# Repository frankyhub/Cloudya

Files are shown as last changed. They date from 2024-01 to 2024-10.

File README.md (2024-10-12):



<div align="center">

|[:skull:ISSUE](https://github.com/frankyhub/Cloudya/issues?q=is%3Aissue)|[:speech_balloon: Forum /Discussion](https://github.com/frankyhub/Cloudya/discussions)|[:grey_question:WiKi](https://github.com/frankyhub/Cloudya/wiki)||
|--|--|--|--|
| | | | |
||<a href="https://github.com/frankyhub/Cloudya/issues">|<a href="https://github.com/frankyhub/Cloudya/discussions">|<a href="https://github.com/frankyhub/Cloudya/releases">|
|| <a href="https://github.com/frankyhub/Cloudya/pulse" alt="Activity">| <a href="https://github.com/frankyhub/Cloudya/graphs/traffic">  |<a href="https://github.com/frankyhub?tab=stars"> |
</div>

# Cloudya
Internetuhr, Wetterstation und RGB-Cloud

## Story
Diese Anleitung beschreibt den Aufbau der Internetuhr "Cloudya". Sie beinhaltet die Internetzeit, Sommer/Winterzeitumstellung, Weckfunktion, eine RGB-LED Cloud, einen WLAN-Manager und einen WEB-Server. Die Zeit- und Datumsanzeige erfolgt über ein 4-Digit TM1637 Display und ein OLED-Display. Die RGB-LED Cloud ist über den WEB-Server steuerbar, ebenso die Weckzeit, die Helligkeit des Displays und der RGB-LEDs.
Für die Einstellung der WLAN-Daten steht ein WLAN-Manager zur Verfügung. Nachdem in den Netzwerkeinstellungen des Handys/Tablet die "Cloudya" ausgewählt wurde, kann über die IP-Adresse 192.168.4.1 der WLAN-Manger gestartet und die WLAN-Zugangsdaten eingetragen werden. Sind die WLAN-Zugangsdaten korrekt, startet Claudya automatisch. Über die angezeigte IP-Adresse im OLED-Display ist der WEB-Server aufrufbar. Die Einstellungen sind jetzt über den WEB-Server möglich.

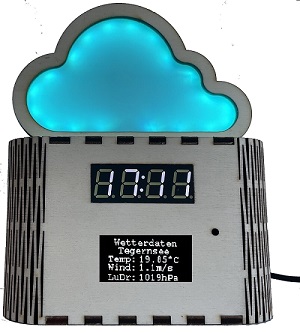
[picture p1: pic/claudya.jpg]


### Hardware

| Anzahl | Bezeichnung | 
| --- | --- |
|  1 | ESP32 NodeMCU D1 R32 |
|  1 |  ESP32 NodeMCU D1 R32 Shield |
|  1 |  Sperrholzplatte 300x600 x 4mm  |
|  1 | Cloudfolie weiß DIN A4 |
| 8  |  Platinenhalter (3D-Druck) |
|  2 | KY-012 Piezo Buzzer |
|  1 |  4-digits TM1637 Display 0,56" weiß  |
|  1 |  1,3 Zoll OLED Display I2C SSH1106 Chip  |
|  1 |  WS2812B LED Strip (NeoPixel)  |
| 1  | JST Stecker/Buchse |
| 1  | 4polige Crimpverbindung |
|  2 |  Stift/Buchsenleiste  |
| | Schaltdraht, Kleber, Kleinmaterial |
| ---  | --- |

### Aufbau und Montage

#### Die Cloud-Vorlage für den Lasercutter besteht aus:

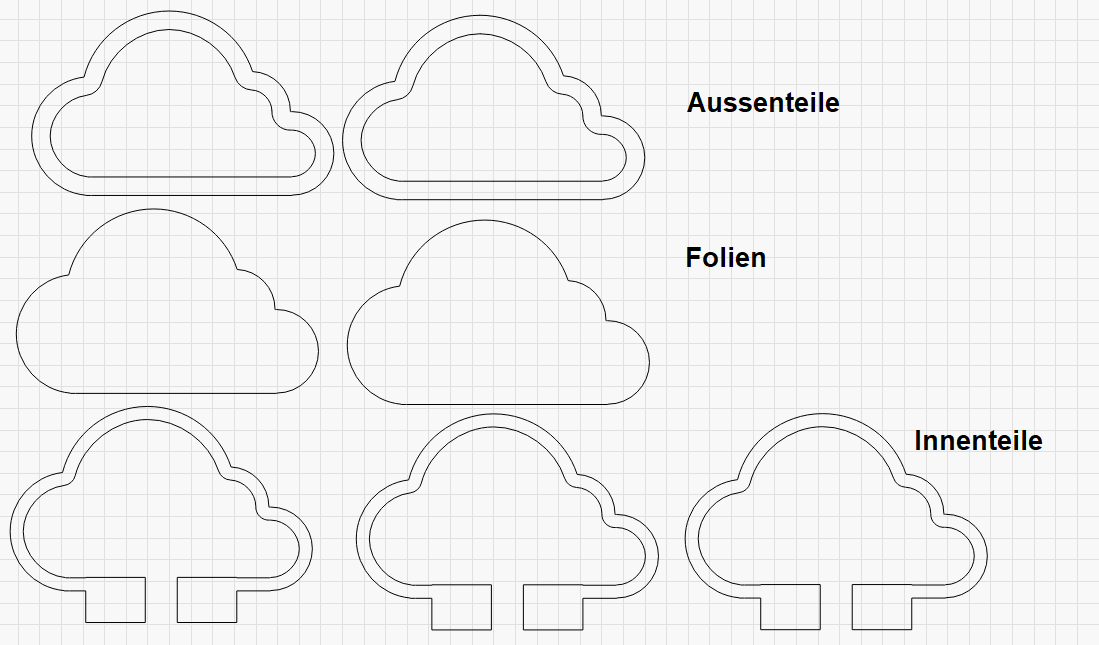
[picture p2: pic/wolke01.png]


### Die fertige Wolke besteht aus 5 Einzelteilen (4mm Sperrholz, L=140, Dicke: 20mm) und 2 Wolkenfolien:

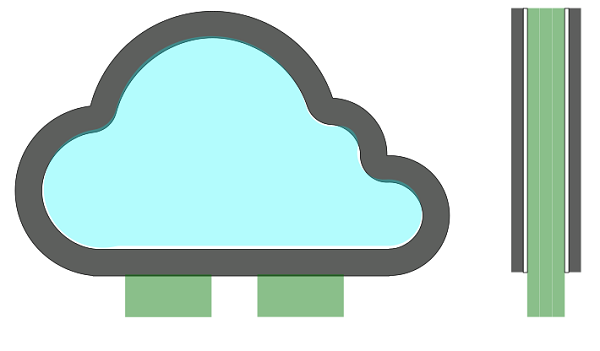
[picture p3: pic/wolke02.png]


### Erstelle die Wolkenteile mit Inkscape:

Zeichne mit den Abmessungen 140x85mm die Kreise der Wolke und unten ein Rechteck.

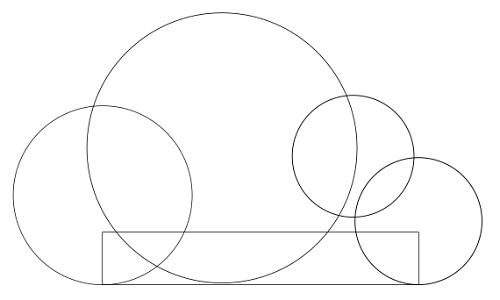
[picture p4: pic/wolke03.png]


### Markiere alles und bilde die Vereinigung. Pfad, Vereinigung (Strg++).

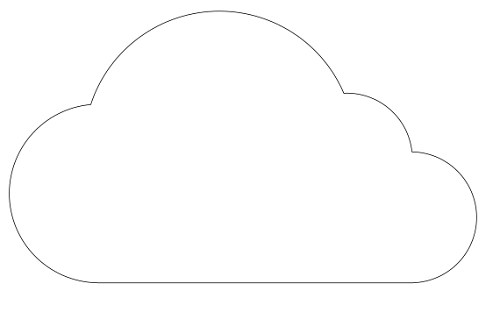
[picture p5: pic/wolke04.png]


### Dupliziere die Wolke 3x (Strg+D): 1x Sicherheitskopie und lege 2 Wolken deckungsgleich übereinander. Wähle eine Wolke aus und bilde den dynamischen Versatz. Pfad - Dynamischer Versatz (Strg+J)

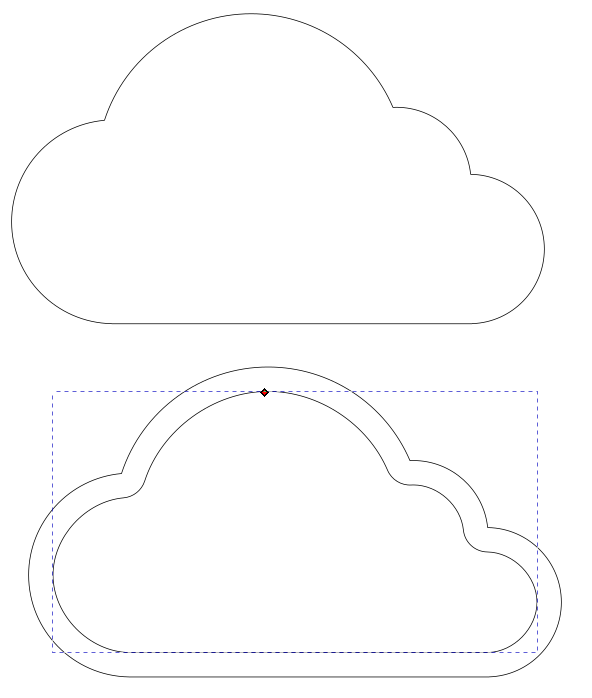
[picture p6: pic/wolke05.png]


### Markiere alles und bilde die Differenz - Pfad-Differenz (Strg+-). Dupliziere die Wolke 2x (Strg+D).

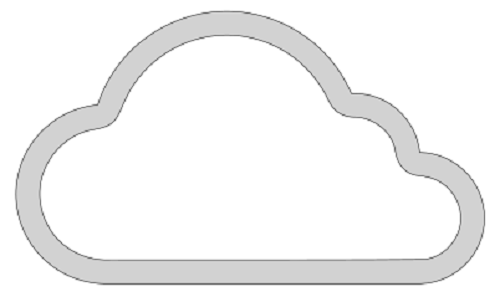
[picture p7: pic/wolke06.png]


### Erstelle mit der ersten Sicherheitskopie eine weitere Wolke mit einem kleineren Rand. Verwende erneut den dynamischen Versatz (Strg+J). Kopiere die Wolke 2x

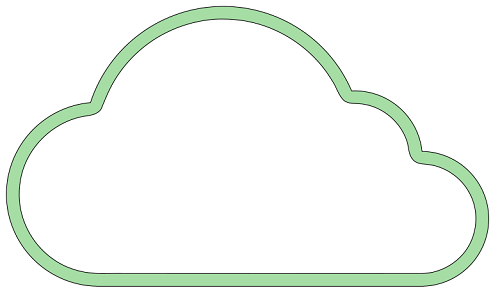
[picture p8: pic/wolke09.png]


### Zeichne ein Rechteck mit den Maßen 70x21mm und lege es unten auf die innere Wolke. Verbinde den schmalen Rahmen mit dem Rechteck- Pfad Vereinigung (Strg++)

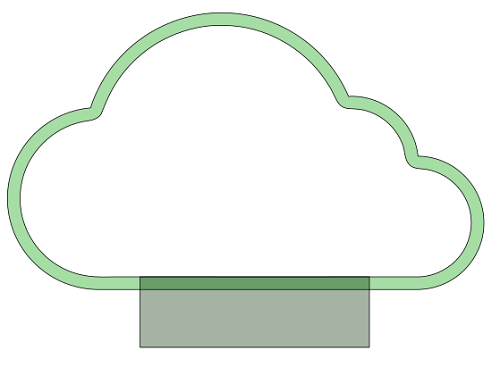
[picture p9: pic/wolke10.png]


### Zeichen ein Rechteck mit 15mm Breite, lege es mittig in die Wolke und bilde die Differenz (Strg+-)

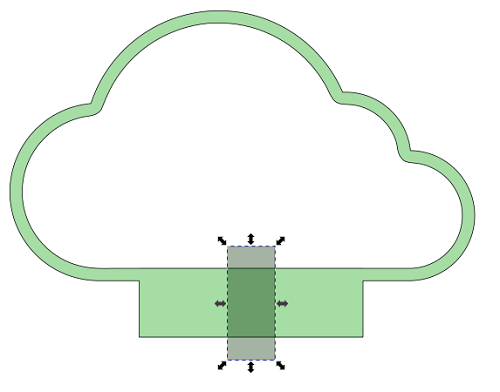
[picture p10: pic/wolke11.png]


### Kopiere die Wolke 3x

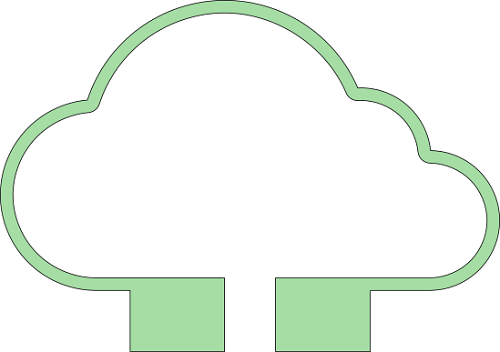
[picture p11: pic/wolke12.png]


### Jetzt sind alle Einzelteile fertig gezeichnet. Fertige von allen Zeichnungen eine Kopie und lege sie zur Kontrolle übereinander. Die Konturen der Wolken müssen deckungsgleich sein.

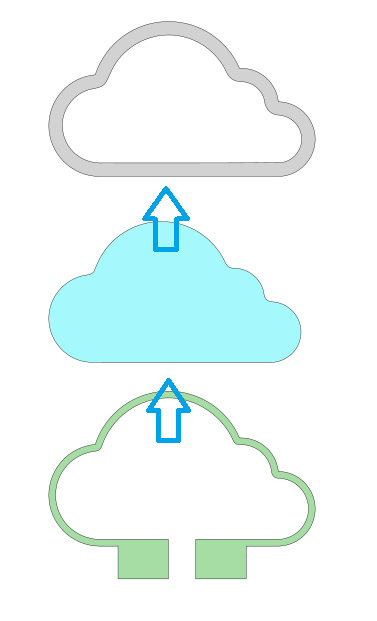
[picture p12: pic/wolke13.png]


### Die Wolken-Elemente liegen jetzt übereinander

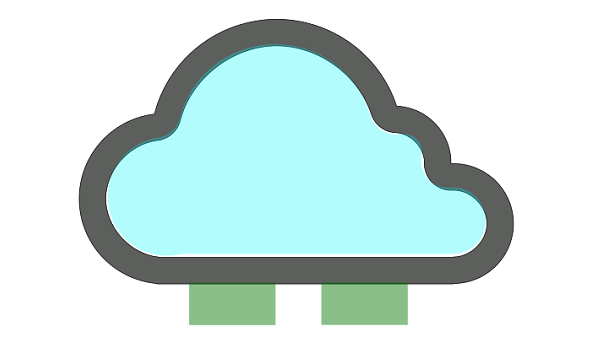
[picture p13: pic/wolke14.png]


### Jetzt sind alle Wolkenteile als Vorlage für den Lasercutter erstellt

Bild

### 3D-Druck, sieben Abstandshalter drucken
+ Die Abstandshalter tragen den ESP32, das 4-Digit-Display und das OLED-Display. Sie werden auf den ESP32, auf das 4-Digit-Display und auf das OLED-Display geklebt..
+ Erstelle die Abstandshalter mit Tinkercad.
+ Der Abstandshalter für das OLED-Display hat die Maße 44x34x2mm Der 1. Durchbruch hat das Maß 36x24x2 und der 2. Durchbruch hat das Maß 2x17x50

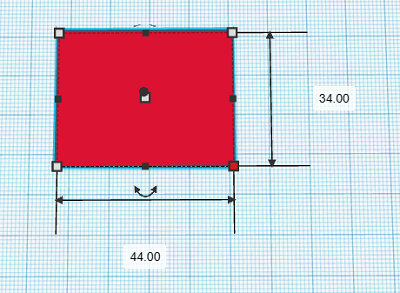
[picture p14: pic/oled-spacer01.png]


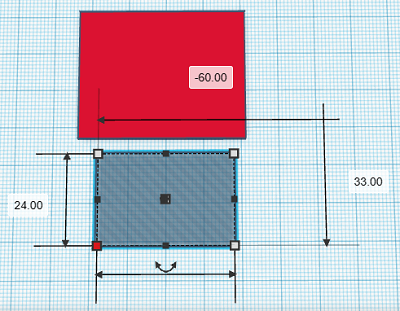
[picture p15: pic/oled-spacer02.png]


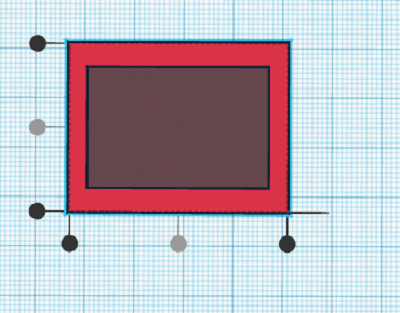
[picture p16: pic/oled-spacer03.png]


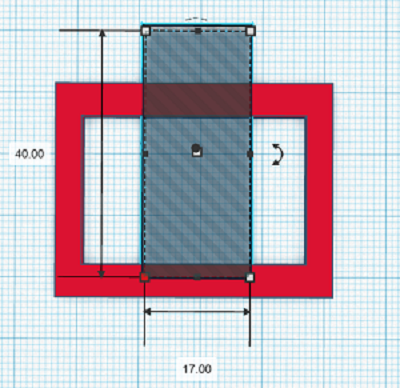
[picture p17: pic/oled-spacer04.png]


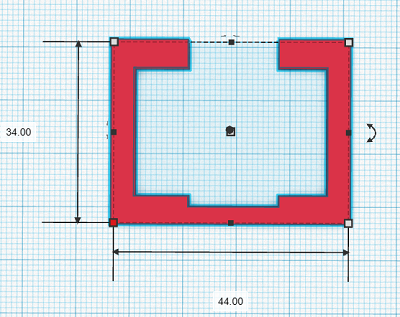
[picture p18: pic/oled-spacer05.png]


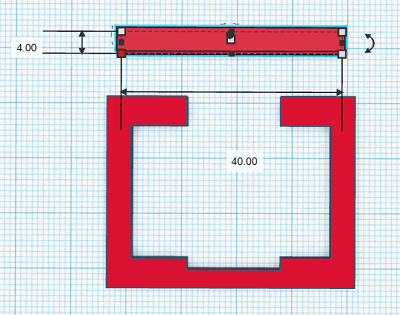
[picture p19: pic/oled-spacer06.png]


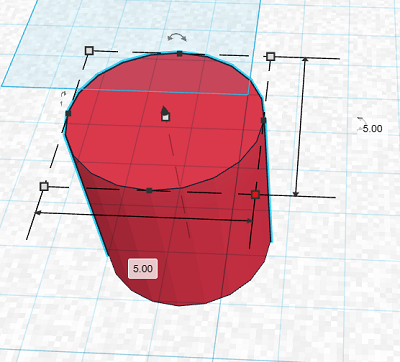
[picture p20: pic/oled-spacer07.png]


## Verdrahtung
+ OLED-Display 1,3": VDD an V, GND an G, SCK an SCL, SDA an SDA,
+ 4-stellige LED 0.56 Display: CLK an D18, DIO an D5, 5V an 5V, GND an GND
+ LED-Stripe: Data an D14, 5V an 5V, GND an GND
+ Buzzer Wecken  D4 und GND
+ Buzzer Gas D26 und GND
+ led_rot 25
+ led_gelb 17
+ led_gruen 16
+ DHT11  5V, GND, OUT an IO27
+ Gas Sensor MQ135 IO39 AO an IO39, 5V und GND; MQ135 eichen!

### ESP32 Shield

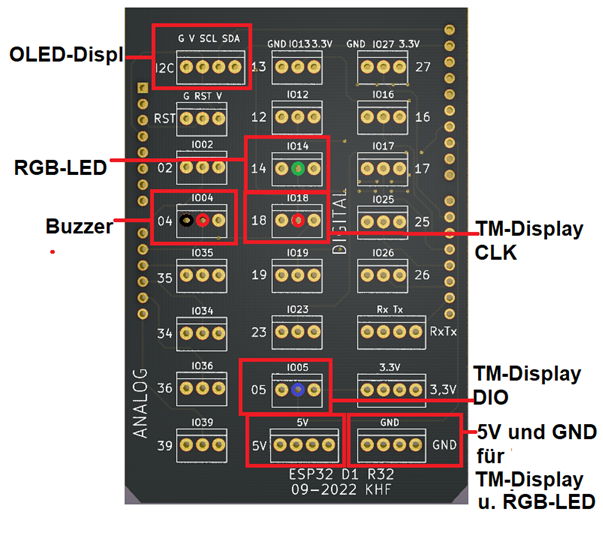
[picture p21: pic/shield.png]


### LED Display

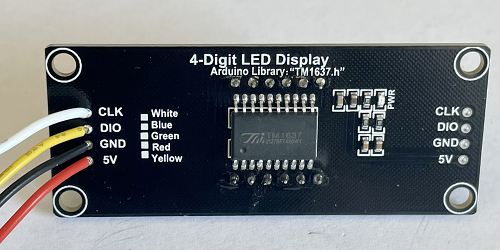
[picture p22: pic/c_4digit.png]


  ### DHT11

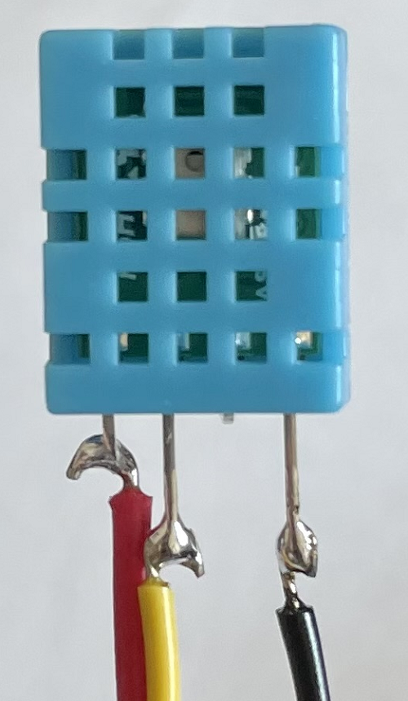
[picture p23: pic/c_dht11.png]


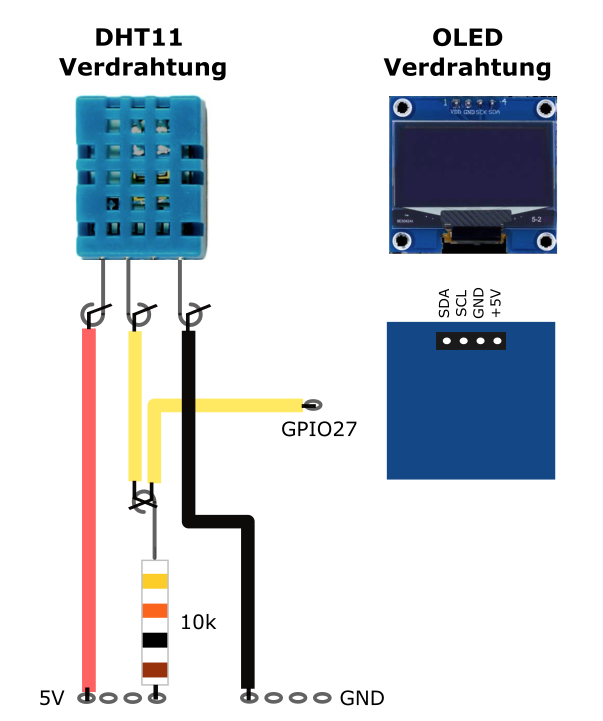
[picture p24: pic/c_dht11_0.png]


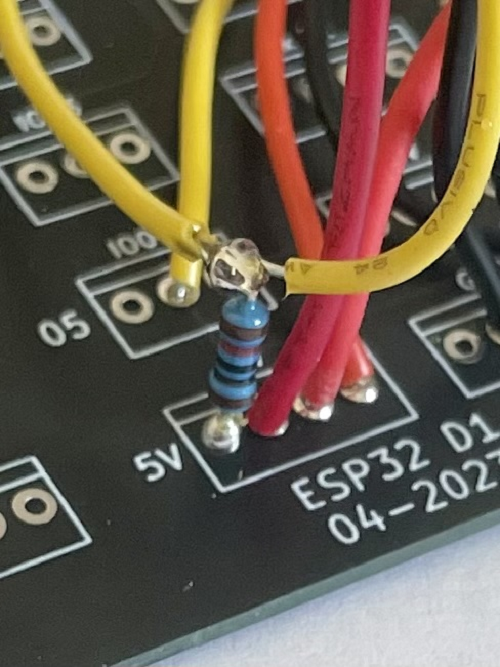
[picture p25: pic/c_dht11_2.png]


  ### LED Stripe

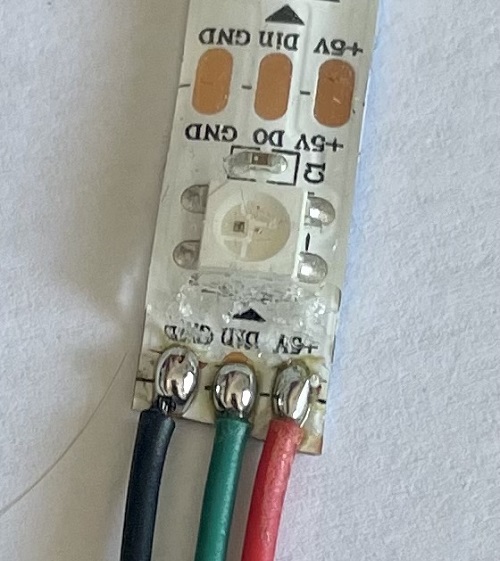
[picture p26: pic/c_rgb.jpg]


### Inbetriebnahme:

  1. Versorge deine Cloudya mit Strom
  2. Warte bis das "Cloudya" WLAN erscheint (Einstellungen, WLAN, Meine Netzwerke)
  3. Verbinde dich mit dem "Cloudya" WLAN und gebe 192.168.4.1 in der Adresszeile deines Webbrowsers ein (KEINE WEB/GOOGLE SUCHE)
  4. Du solltest jetzt ein Webinterface sehen in dem du den Namen und das Passwort deines Heimnetzwerks eingeben kannst
  5. Wenn du jetzt "Speichern" drückst, sollte sich deine Cloudya mit deinem Heimnetzwerk verbinden
  6. Die IP Adresse wird nach dem Reboot im OLED Display und im Seriellen Monitor angezeigt.
  7. Du kannst jetzt das Webinterface zur Steuerung des Lichts etc. aufrufen indem du die IP Adresse deiner Cloudya in der Adresszeile deines Webbrowsers eingibst.

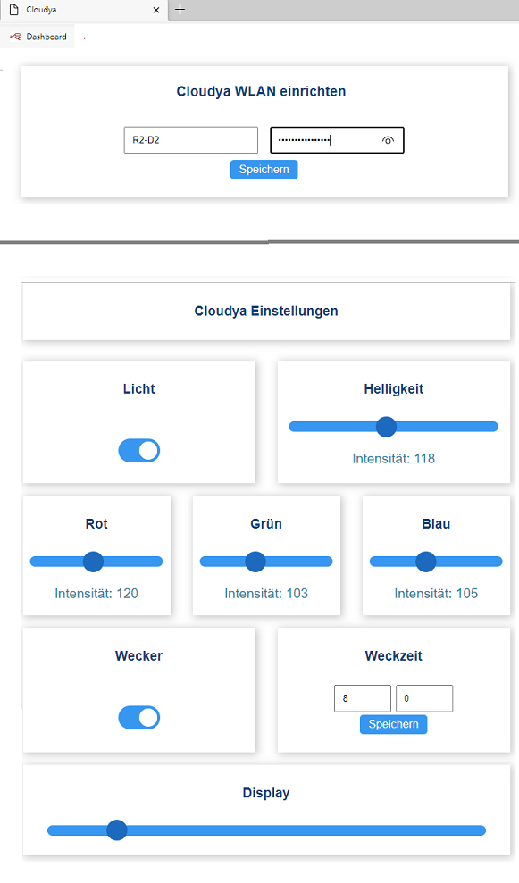
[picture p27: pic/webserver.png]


---

<div style="position:absolute; left:2cm; ">   
<ol class="breadcrumb" style="border-top: 2px solid black;border-bottom:2px solid black; height: 45px; width: 900px;"> <p align="center"><a href="#oben">nach oben</a></p></ol>
</div>  

---

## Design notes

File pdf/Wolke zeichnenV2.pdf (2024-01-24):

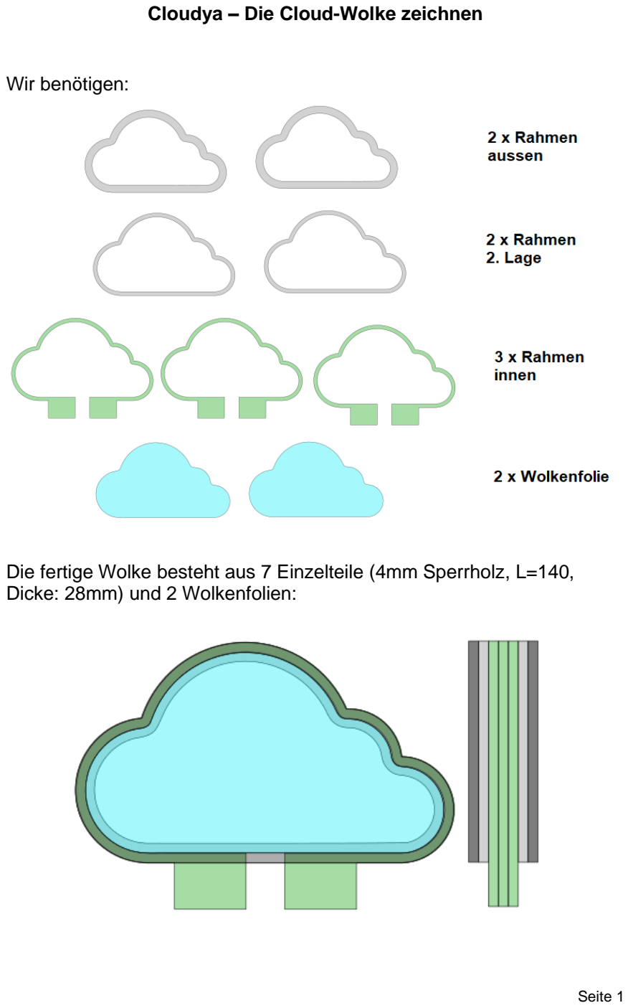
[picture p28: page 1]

Cloudya – Die Cloud-Wolke zeichnen

Wir benötigen:

Die fertige Wolke besteht aus 7 Einzelteile (4mm Sperrholz, L=140, Dicke: 28mm) und 2 Wolkenfolien:

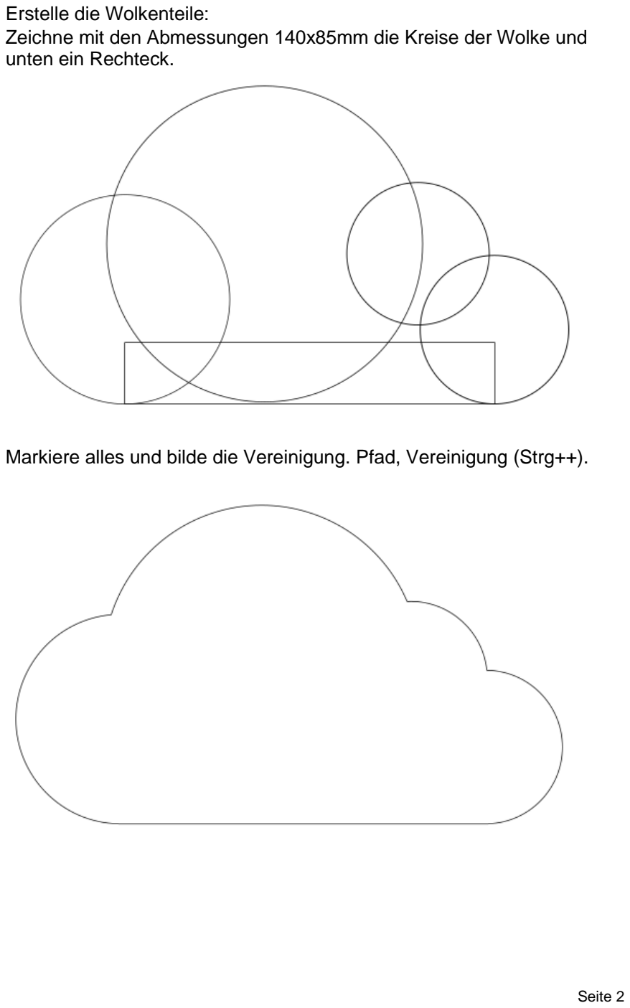
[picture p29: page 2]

Erstelle die Wolkenteile:
Zeichne mit den Abmessungen 140x85mm die Kreise der Wolke und unten ein Rechteck.

Markiere alles und bilde die Vereinigung. Pfad, Vereinigung (Strg++).

Dupliziere die Wolke 3x (Strg+D): 1x Sicherheitskopie und lege 2 Wolken deckungsgleich übereinander. Wähle eine Wolke aus und bilde den dynamischen Versatz. Pfad – Dynamischer Versatz (Strg+J)

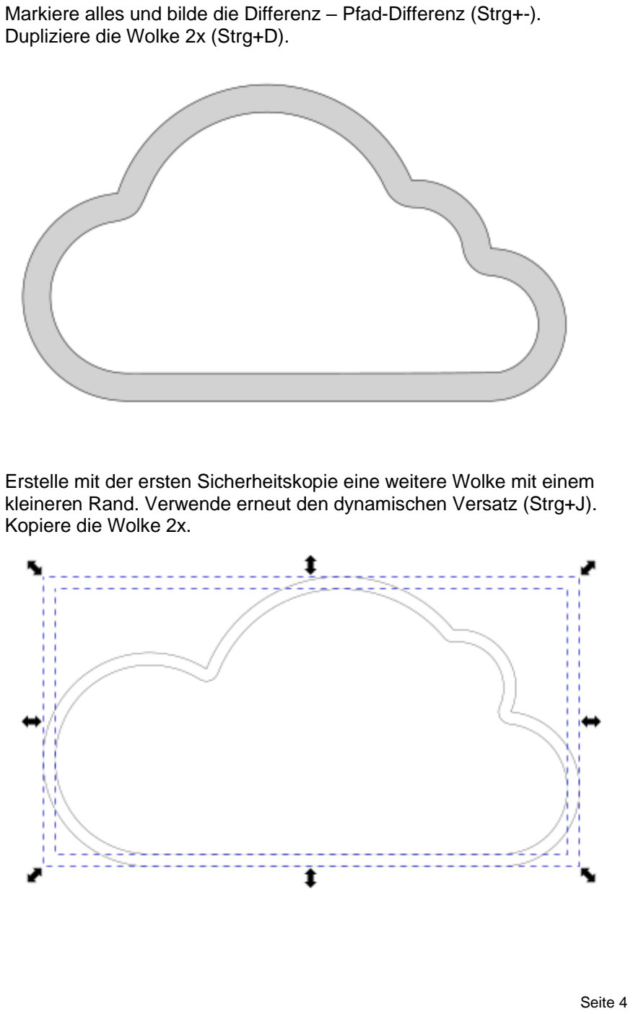
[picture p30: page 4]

Markiere alles und bilde die Differenz – Pfad-Differenz (Strg+-). Dupliziere die Wolke 2x (Strg+D).

Erstelle mit der ersten Sicherheitskopie eine weitere Wolke mit einem kleineren Rand. Verwende erneut den dynamischen Versatz (Strg+J). Kopiere die Wolke 2x.

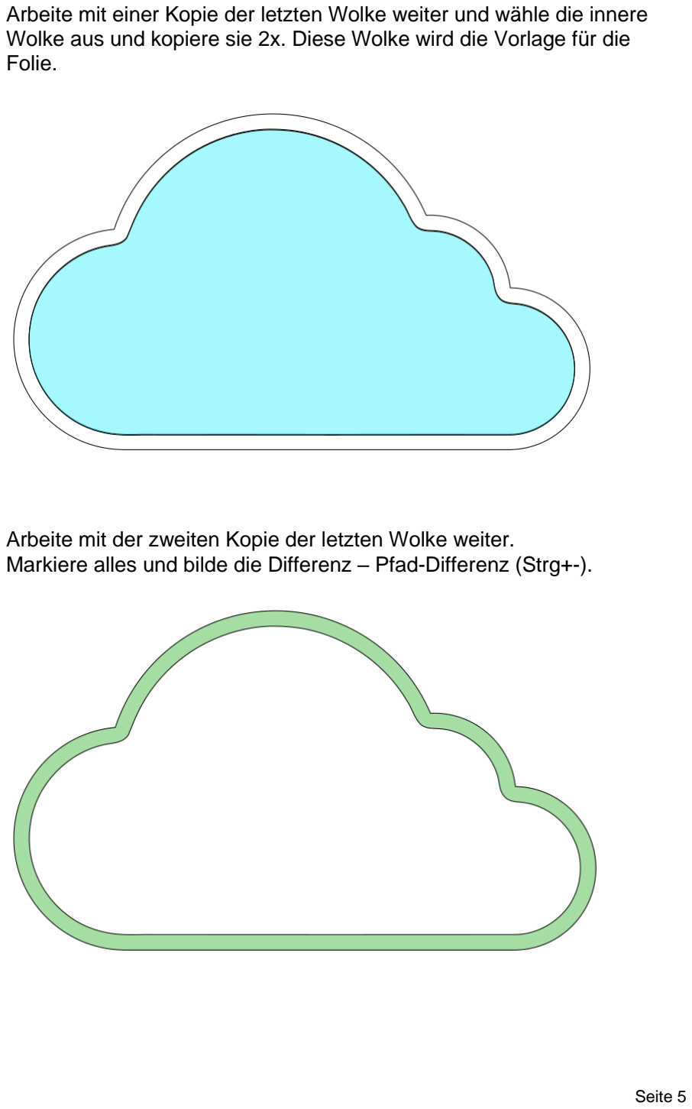
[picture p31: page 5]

Arbeite mit einer Kopie der letzten Wolke weiter und wähle die innere Wolke aus und kopiere sie 2x. Diese Wolke wird die Vorlage für die Folie.

Arbeite mit der zweiten Kopie der letzten Wolke weiter. Markiere alles und bilde die Differenz – Pfad-Differenz (Strg+-).

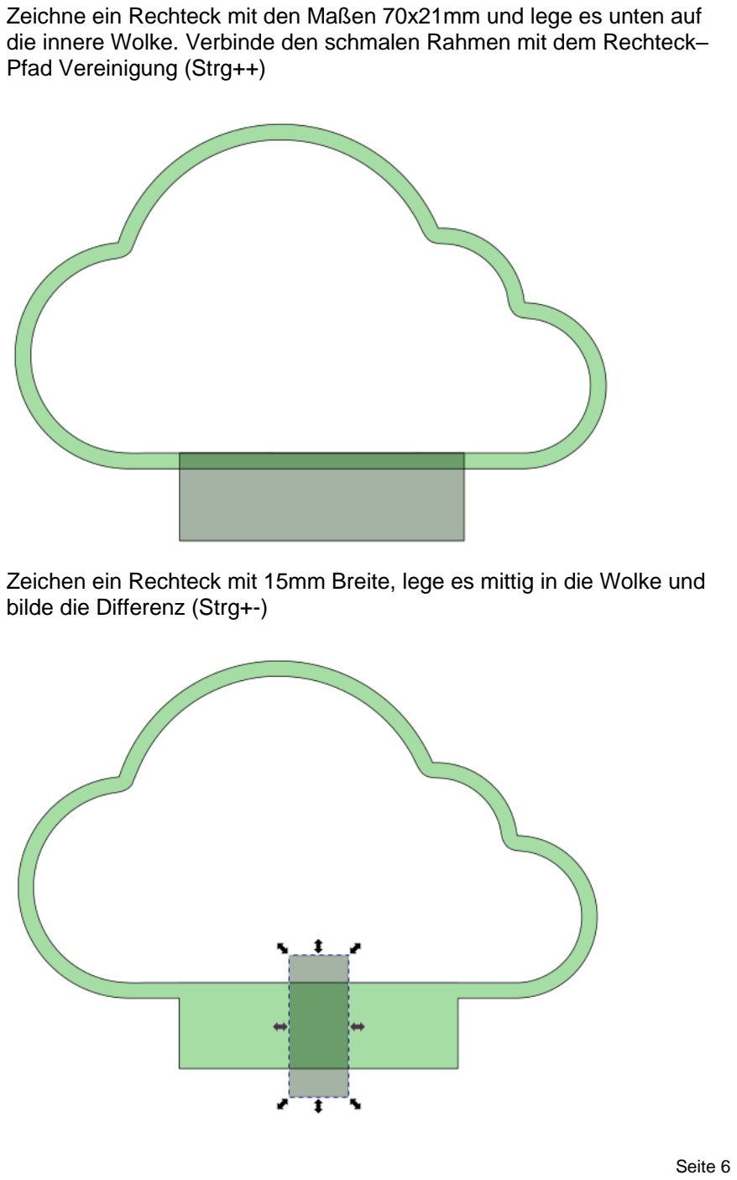
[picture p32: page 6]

Zeichne ein Rechteck mit den Maßen 70x21mm und lege es unten auf die innere Wolke. Verbinde den schmalen Rahmen mit dem Rechteck– Pfad Vereinigung (Strg++)

Zeichen ein Rechteck mit 15mm Breite, lege es mittig in die Wolke und bilde die Differenz (Strg+-)

Kopiere die Wolke 3x.

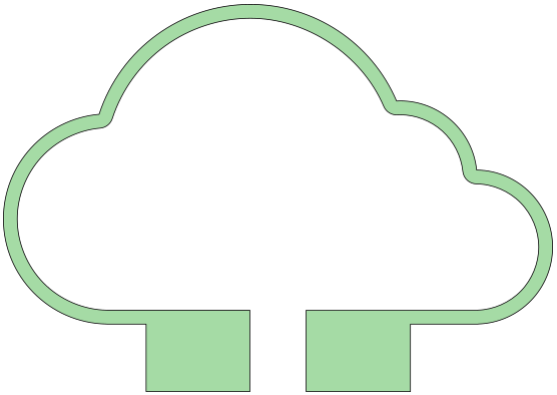
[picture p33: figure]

Jetzt sind alle Einzelteile fertig gezeichnet. Fertige von allen Zeichnungen eine Kopie und lege sie zur Kontrolle übereinander. Die Konturen der Wolken müssen deckungsgleich sein.

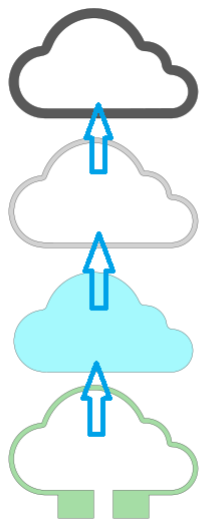
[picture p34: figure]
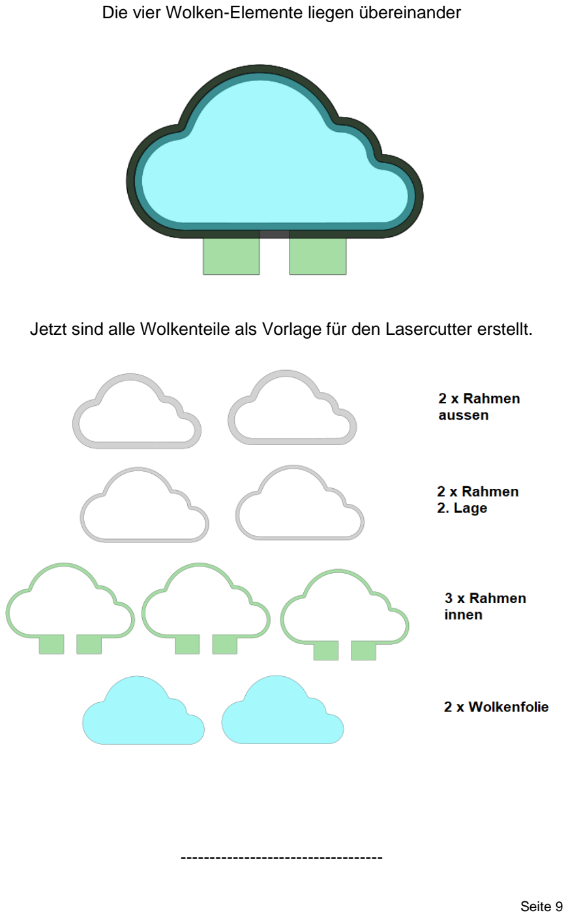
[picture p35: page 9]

Die vier Wolken-Elemente liegen übereinander

Jetzt sind alle Wolkenteile als Vorlage für den Lasercutter erstellt.

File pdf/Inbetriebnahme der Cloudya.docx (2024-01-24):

Inbetriebnahme der Cloudya

Die Cloudya zeigt die Uhrzeit, Datum, Raumtemperatur, Luftfeuchte und die aktuellen Wetterdaten in einem OLED-Display an und aktualisiert alles in regelmäßigen Abständen, Damit das funktioniert benötigt die Cloudya einen WLAN-Zugang.

Die Cloudya beinhaltet einen WiFi-Manager für die Einstellung der WLAN-Zugangsdaten (SSID und Passwort). Nach dem ersten Start der Cloudya, muss in den WLAN-Einstellungen des Handys, PC oder Tablet das Netzwerk " Cloudya " ausgewählt und über einen Browser die IP-Adresse 192.168.4.1 aufgerufen werden.

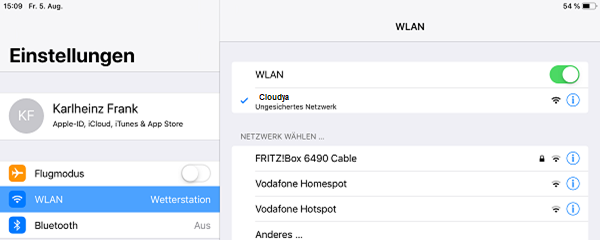
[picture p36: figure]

Danach startet "Cloudya WLAN einrichten" und die Zugangsdaten für das WLAN können eingetragen werden.

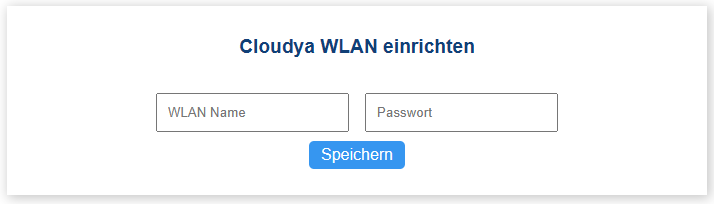
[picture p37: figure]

Sind die Zugangsdaten korrekt, startet Cloudya.
Die Cloudya zeigt beim Start für 5 Sekunden einen Smiley. In dieser Zeit werden die aktuelle Uhrzeit, das Datum und die aktuellen Wetterdaten aus der Region von de.pool.ntp.org und von openweathermap.org geladen.
Sind die Daten geladen, verschwindet der Smiley und es werden in regelmäßigen Abständen die Seiten mit Datum und Uhrzeit, die Wetterdaten der Region Tegernsee und das Raumklima mit Temperatur und Luftfeuchte angezeigt.

Auf der Startseite des OLED-Displays steht unten die IP Adresse für den Cloudya WEB-Server. Mit Eingabe dieser IP-Adresse in den Browser startet der Cloudya WEB-Server für die Einstellung des Weckers, der RGB-Farben und der Display-Helligkeit.

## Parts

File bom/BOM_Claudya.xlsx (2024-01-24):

 | BOM Claudya
Menge | Bezeichnung | Lieferant | Kosten | Kosten/Einheit
10 | ESP32 NodeMCU D1 R32 | AZ-Delivery (https://www.az-delivery.de/products/esp32-d1-r32-board) | 68.00 € | 6.80 € |  | YIXISI 20 Pairs JST SM 4PIN Stecker Männlich zu Weiblich EL Draht Kabel Stecker Adapter,2 Pin Stecker Männlichen und Weiblichen Steckverbinder Adapter mit 150 mm Elektrisch Kabel für LED Licht : Amazon.de: Baumarkt (https://www.amazon.de/gp/product/B08JV9L48T/ref=ox_sc_act_title_1?smid=A6CSVRKTUBQZZ&psc=1)
10 | KY-012 aktives Piezo Buzzer Alarm | Amazon (https://www.amazon.de/QWORK-Elektronischer-Summer-Active-Kabell%C3%A4nge/dp/B09RFH1T8J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) | 10.60 € | 0.50 €
10 | 4-Digit_LED-Display 0,56" TM1637 weiß | AliExpress (https://de.aliexpress.com/item/32838969764.html) | 19.54 € | 1.96 €
10 | WS2812B LED Strip (NeoPixel) | Amazon (https://www.amazon.de/dp/B01CDTEH3Q?aaxitk=82f2b46c5d5888f2d76393f048307f25&hsa_cr_id=3920940390402&pd_rd_pl) | 25.00 € | 2.50 €
10 | Polystyrol-Folie 0,5mm Art.Nr 0113648 | Modulor (https://www.modulor.de/polystyrol-weiss-matt-0-50-x-495-x-1000-nutzmass.html) | 9.50 € | 0.95 €
10 | TUOFENG 22 awg Volldraht | Amazon (https://www.amazon.de/TUOFENG-Volldraht-Volldraht-Kit-6-verschiedenfarbige-9-Meter-Spulen-Gauge-%C3%9Cberbr%C3%BCckungsdraht-Auflegungsdraht-Kit/dp/B07V5FVSYL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) | 21.00 € | 2.10 €
10 | 1,3 Zoll OLED Display I2C SSH1106 Chip | Amazon (https://www.amazon.de/AZDelivery-Display-Arduino-Raspberry-Gratis/dp/B07V9SLQ6W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) | 54.00 € | 5.40 €
10 | Stecker Netzteil für USB - HUB 7.5V, 2A Adapter Netzstecker Hohlstecker 5,5x2,1mm #417 | Amazon (https://www.amazon.de/SM-PC%C2%AE-Stecker-Netzteil-f%C3%BCr-USB/dp/B07S49STJD) | 70.00 € | 7.00 €
10 | JST Stecker Buchse | Amazon (https://www.amazon.de/gp/product/B08JV9L48T/ref=ppx_yo_dt_b_asin_image_o00_s00?ie=UTF8&psc=1) | 10.00 € | 1.00 €
10 | Platinenbuchsen | ebay (https://www.ebay.de/itm/283417689728)
10 | ESP32 Shield | JLCPBC | 20.00 € | 2.00 €
10 | Gehäuse Sperrholz 4mm | Laser cut |  | 5.00 €
10 | Abstandshalter | 3D-print |  | 1.00 €
20 | Stift/Buchsenleiste | Amazon (https://www.amazon.de/gp/product/B07CC4V9ZY/ref=ppx_yo_dt_b_search_asin_image?ie=UTF8&psc=1) | 9.87 € | 0.99 €
 |  |  |  | 37.20 €
 |  |  |  |  | 50 Stück Crimpkontakte für Platinenbuchse Raster 2,54mm | eBay (https://www.ebay.de/itm/283417671990)
 |  |  |  |  | 50 Stück Platinenbuchse Kabel-Platte Raster 2,54mm einreihig 4-polig | eBay (https://www.ebay.de/itm/283417689728)
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

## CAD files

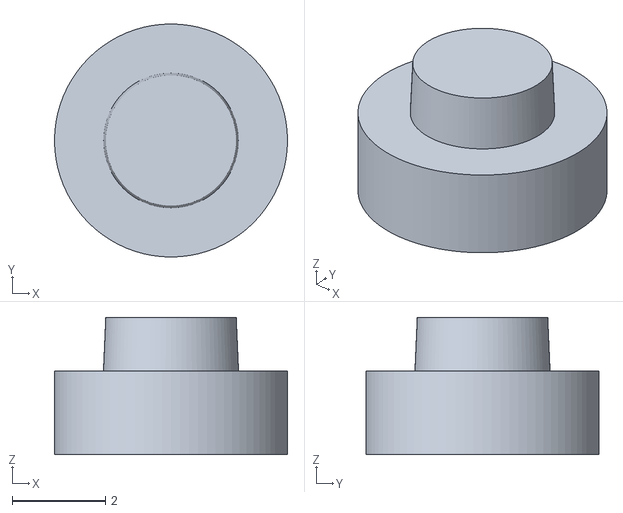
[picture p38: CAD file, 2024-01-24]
3D/Pin-Display.stl
5.00 x 5.00 x 2.95

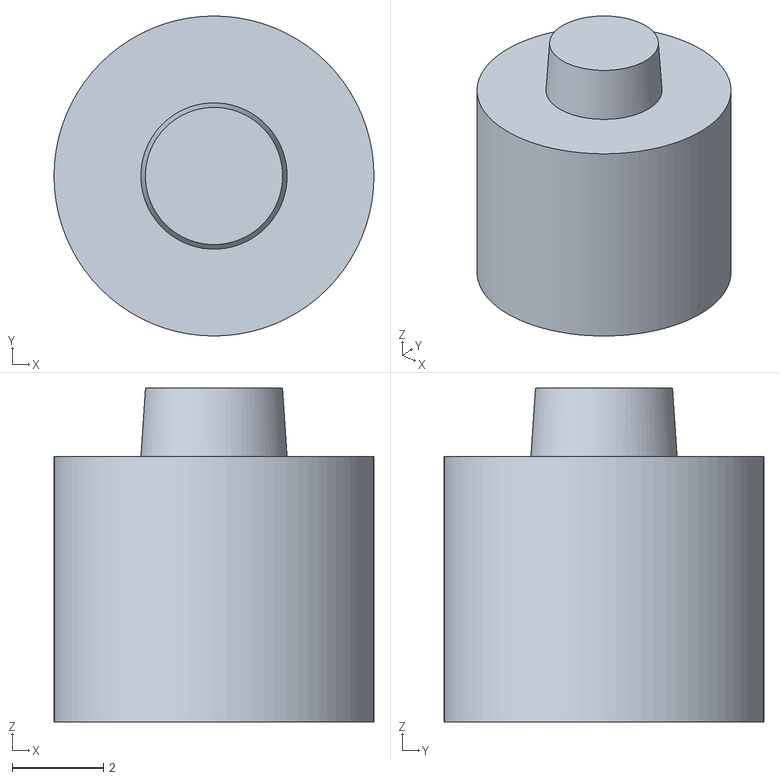
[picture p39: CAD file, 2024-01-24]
3D/Pin-SSegment.stl
7.00 x 7.00 x 7.30

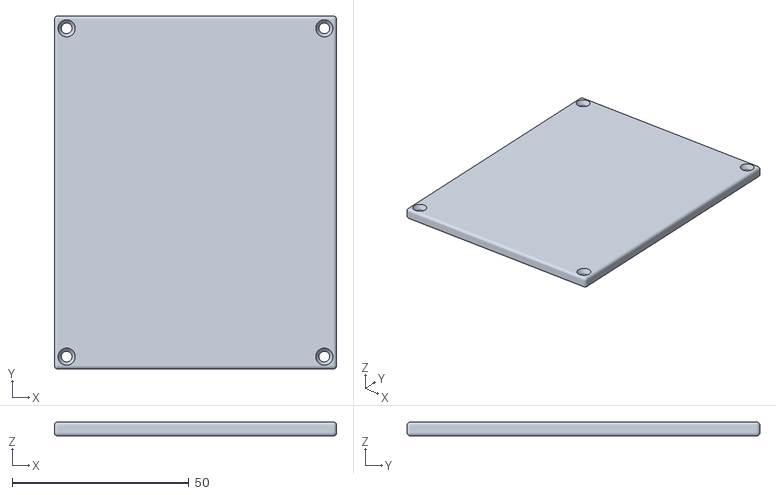
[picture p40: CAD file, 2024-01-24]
3D/Deckel-Time Cloud.stl
80.0 x 100.0 x 4.00

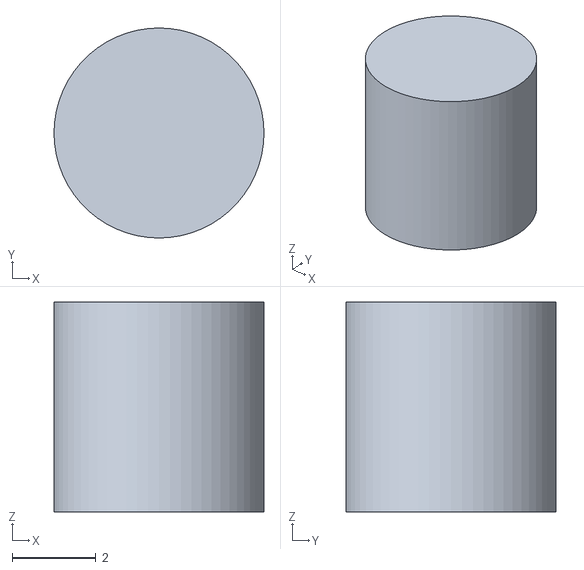
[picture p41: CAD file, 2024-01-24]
3D/Pin 5x5.stl
5.00 x 5.00 x 5.00

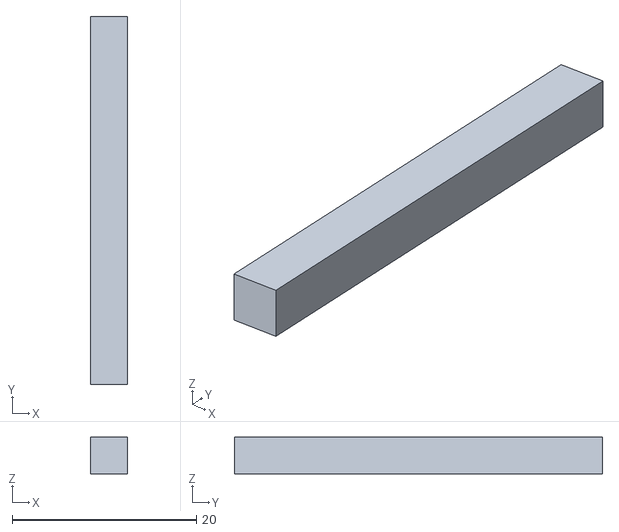
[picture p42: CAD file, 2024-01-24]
3D/TM-Spacer.stl
4.00 x 40.0 x 4.00

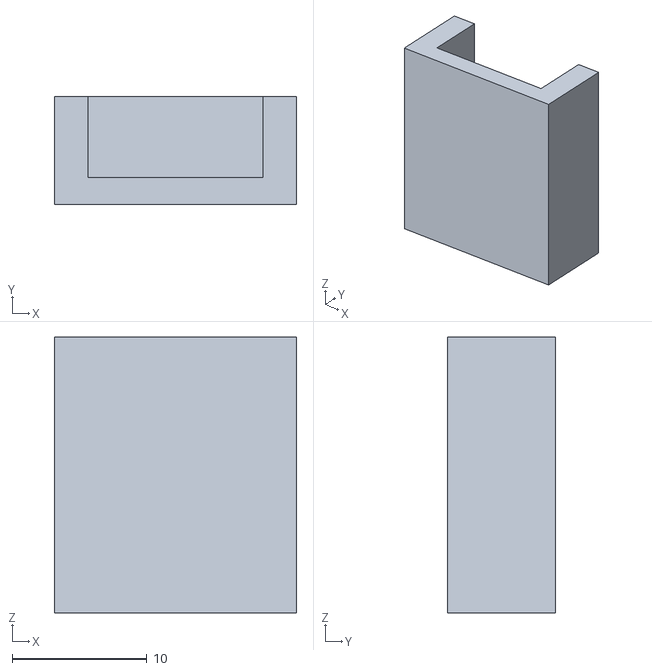
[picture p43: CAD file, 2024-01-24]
3D/DHT11-Halter.stl
18.0 x 8.00 x 20.5

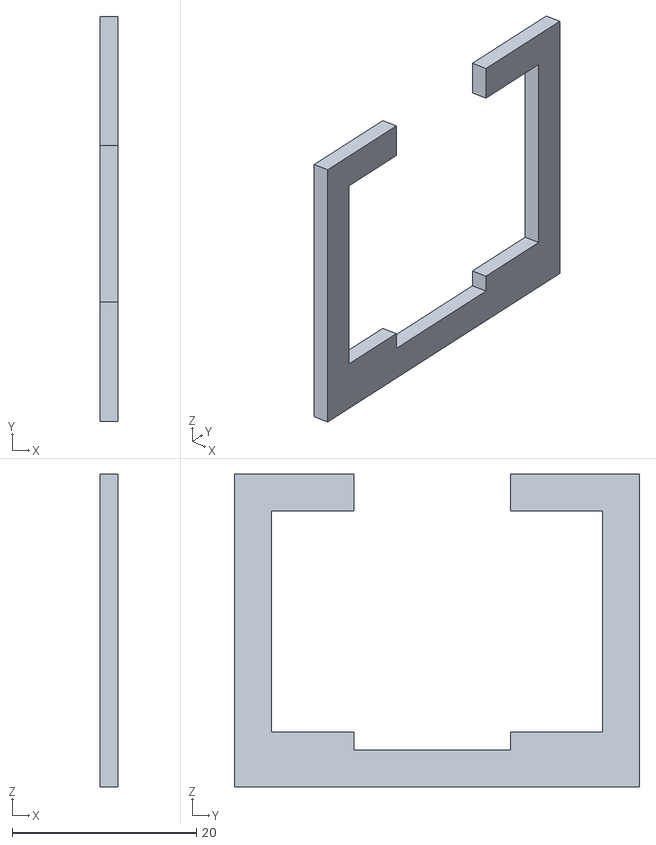
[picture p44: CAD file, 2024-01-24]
3D/OLED-Spacer1.stl
2.00 x 44.0 x 34.0

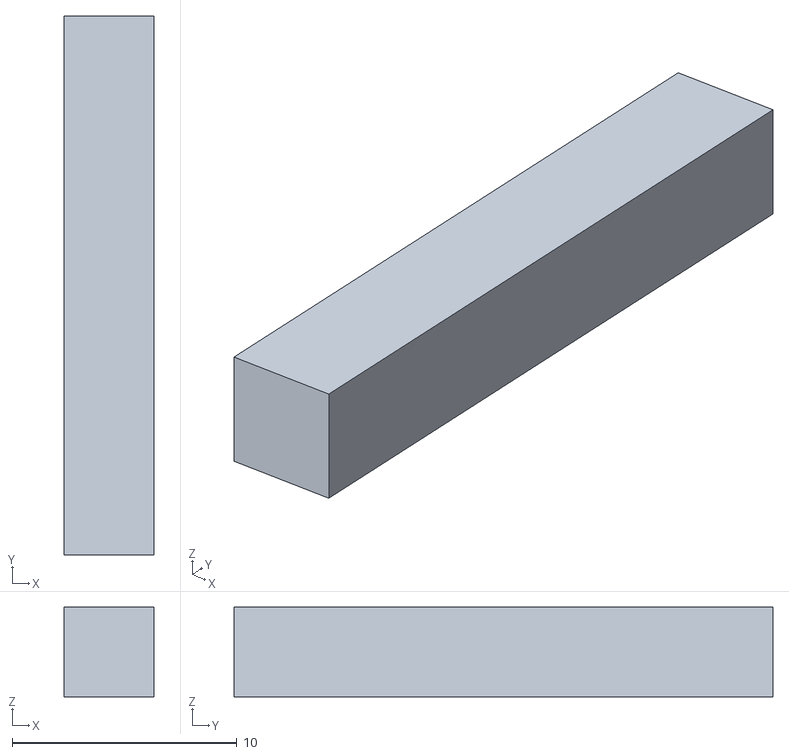
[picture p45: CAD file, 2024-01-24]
3D/alex-Spacer.stl
4.00 x 24.0 x 4.00

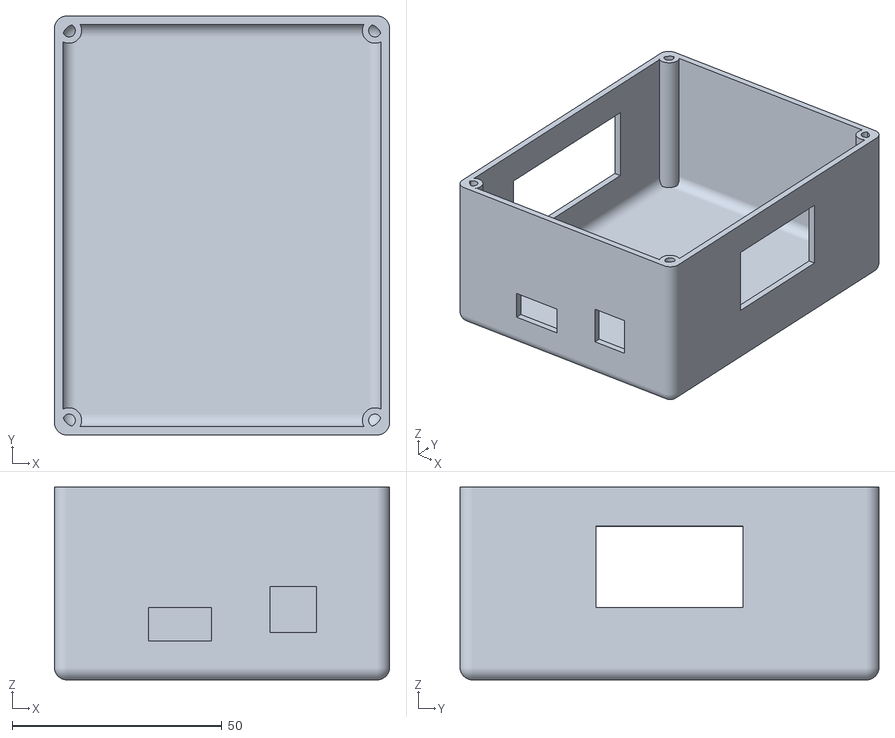
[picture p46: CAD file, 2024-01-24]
3D/Box-Cloudya.stl
80.0 x 100.0 x 46.0

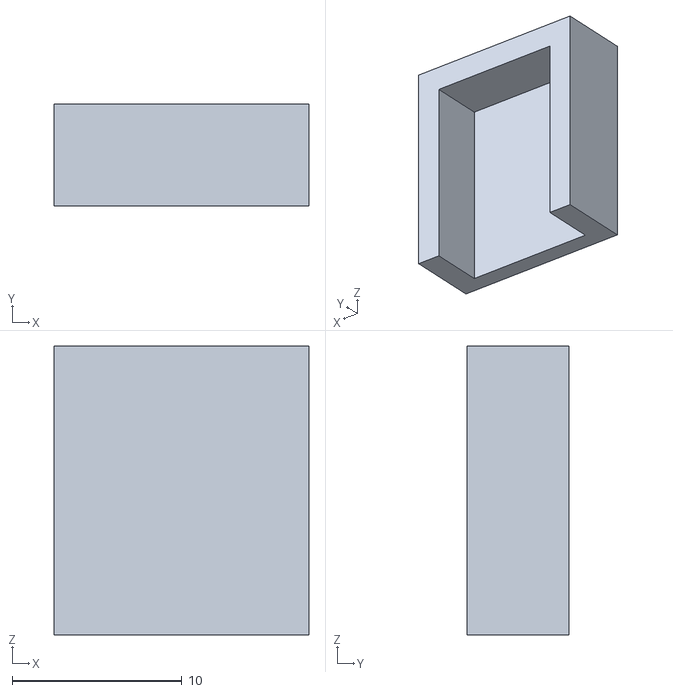
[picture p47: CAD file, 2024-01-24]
3D/DHT11-Halter_klein.stl
15.0 x 6.00 x 17.0

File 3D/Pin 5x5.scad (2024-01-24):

$fn=60;
cylinder(h=5,d=5);

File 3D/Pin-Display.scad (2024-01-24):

//Platinen Pin 

$fn=80;
Rgr = 2.5;  //Radius PIN 
R1kl = 1.5; //Radius 1 Stift
R2kl = 1.4; //Radius 2 Stift
Sh = 1.8;     //Sockelhöhe

color("WhiteSmoke")
cylinder(h = Sh, r1=Rgr , r2=Rgr , center = true); //Sockel
translate(v = [0, 0, Sh/2])
color("WhiteSmoke")
cylinder(h = 2.3, r1 = R1kl, r2 = R2kl, center = true); //Pin

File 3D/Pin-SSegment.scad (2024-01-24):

//Platinen Pin 

$fn=80;
Rgr = 3.5;  //Radius PIN 
R1kl = 1.7; //Radius 1 Stift
R2kl = 1.5; //Radius 2 Stift
Sh = 5.8;     //Sockelhöhe

color("WhiteSmoke")
cylinder(h = Sh, r1=Rgr , r2=Rgr , center = true); //Sockel
translate(v = [0, 0, Sh/2])
color("WhiteSmoke")
cylinder(h = 3, r1 = R1kl, r2 = R2kl, center = true); //Pin

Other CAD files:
3D/Deckel-Cloudya.stl
3D/Box-Cloudya.scad
3D/Box-Time Cloud50.scad
3D/DHT11-Halter.scad
3D/DHT11-Halter_klein.scad
3D/OLED-Spacer1.scad
3D/TM-Spacer.scad
3D/box/box_lib.scad
3D/box/compat.scad
3D/box/constants.scad
3D/box/math.scad
3D/box/shapes.scad
3D/box/transforms.scad

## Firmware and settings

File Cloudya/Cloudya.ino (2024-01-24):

/*************************************************************************************************
                                      PROGRAMMINFO
**************************************************************************************************
                                     Cloudya FP2023
  Funktion: ESP32 WEB Server Internet-Uhr, Wecker, LED-Stripe, 4 Digit Display, DHT11 Raumklima, Wetterdaten vom Tegernsee, Gas-Sensor
  OLED Display 1,3" mit Wochentag, Datum, Uhrzeit, Bewölkung und IP-Adresse, Raumklima, Wetterdaten

**************************************************************************************************
  Version: 01.03.2023   Cloudya A155
  ---------------------------------------------------------------

*************************************************************************************************
  Board: ESP32vn IoT UNO
**************************************************************************************************
  C++ Arduino IDE V1.8.19
**************************************************************************************************
  Einstellungen:
  https://dl.espressif.com/dl/package_esp32_index.json
  http://dan.drown.org/stm32duino/package_STM32duino_index.json
  https://raw.githubusercontent.com/espressif/arduino-esp32/gh-pages/package_esp32_dev_index.json
**************************************************************************************************
  Inbetriebnahme:

  1. Versorge deine Cloudya mit Strom
  2. Warte bis das "Cloudya" WLAN erscheint (Einstellungen, WLAN, Meine Netzwerke)
  3. Verbinde dich mit dem "Cloudya" WLAN und gebe 192.168.4.1 in der Adresszeile deines Webbrowsers ein (KEINE WEB/GOOGLE SUCHE)
  4. Du solltest jetzt ein Webinterface sehen in dem du den Namen und das Passwort deines Heimnetzwerks eingeben kannst
  5. Wenn du jetzt "Speichern" drückst, sollte sich deine Cloudya mit deinem Heimnetzwerk verbinden
  6. Die IP Adresse wird nach dem Reboot im OLED Display und im Seriellen Monitor angezeigt.
  7. Du kannst jetzt das Webinterface zur Steuerung des Lichts etc. aufrufen indem du die IP Adresse deiner Cloudya in der Adresszeile deines Webbrowsers eingibst.


  ### Electronik Verbindungen
**OLED-Display 1,3": VDD an V, GND an G, SCK an SCL, SDA an SDA,
**4-stellige LED 0.56 Display: CLK an D18, DIO an D5, 5V an 5V, GND an GND
**LED-Strip: Data an D14, 5V an 5V, GND an GND
**Buzzer Wecken  D4 und GND
**Buzzer Gas D26 und GND
** led_rot 25
** led_gelb 17
** led_gruen 16
** DHT11  5V, GND, OUT an IO27
** Gas Sensor MQ135 IO39 AO an IO39, 5V und GND; MQ135 eichen!
 **************************************************************************************************/

#include <AsyncTCP.h>
#include <ESPAsyncWebServer.h>
#include <ESPmDNS.h>
#include <FastLED.h>
#include <SPIFFS.h>
#include <TM1637Display.h>
#include <WiFi.h>
#include <time.h>
#include "./src/hardware/LightController.h"
#include "./src/network/MDNSController.h"
#include "./src/AlarmController.h"
#include "./src/PasswordController.h"
#include "./src/hardware/System.h"
#include "./src/Webserver.h"

//------------openWeatherMap--------------------------------
#include <HTTPClient.h>
#include <Arduino_JSON.h>
//---------------------------------------------------------


//------- Gas Sensor MQ135 ------------
int Buzzer = 26;
int Gas_analog = 39;
//int Gas_digital = 2;

#define led_rot 25
#define led_gelb 17
#define led_gruen 16
//----------------------------------------


//----------DHT11------------------------------------------
#include <SimpleDHT.h> //by Winlin 1.0.14       
int pinDHT11 = 27;
SimpleDHT11 dht11(pinDHT11);
//---------------------------------------------------------
#include <U8g2lib.h>
#include <Wire.h>

U8G2_SH1106_128X64_NONAME_F_HW_I2C u8g2(U8G2_R0, /* reset=*/ U8X8_PIN_NONE);
unsigned long delayTime;

#include <NTPClient.h>
#include <WiFiUdp.h>
WiFiUDP ntpUDP;
NTPClient timeClient(ntpUDP);

// Variablen
String formattedDate;
String dayStamp;
String timeStamp;
char *name = "Cloudya";
char *hostname = "Cloudya";
char *passwort = "";

// 4-Digit Display
#define CLK 18
#define DIO 5
TM1637Display display = TM1637Display(CLK, DIO);

// Internetzeit
#define MY_NTP_SERVER "de.pool.ntp.org"
#define MY_TZ "CET-1CEST,M3.5.0/02,M10.5.0/03" // https://github.com/nayarsystems/posix_tz_db/blob/master/zones.csv
time_t now;
tm tm;
void showTime() {
  time(&now);
  localtime_r(&now, &tm); // update the structure tm with the current time
  /* Serial.print("Jahr:");
    Serial.print(tm.tm_year + 1900); // years since 1900
    Serial.print("\tmonth:");
    Serial.print(tm.tm_mon + 1); // January = 0 (!)
    Serial.print("\tday:");
    Serial.print(tm.tm_mday); // day of month
    Serial.print("\thour:");
    Serial.print(tm.tm_hour); // hours since midnight 0-23
    Serial.print("\tmin:");
    Serial.print(tm.tm_min); // minutes after the hour 0-59
    Serial.print("\tsec:");
    Serial.print(tm.tm_sec); // seconds after the minute 0-61*
    Serial.print("\twday");
    Serial.print(tm.tm_wday); // days since Sunday 0-6
  */
  Serial.println();
}


MDNSController mdnsController = MDNSController(hostname, name);
LightController lightController = LightController();
AlarmController alarmController = AlarmController(&lightController);
Webserver webserver = Webserver(80, lightController, &alarmController, &display);
Webserver apWebserver = Webserver(80, lightController, &alarmController, &display);

bool isSetup = false;

struct Button
{
  uint8_t pin;
  uint32_t numberKeyPresses;
  bool pressed;
};

Button buttonRight = {12, 0, false};
Button buttonLeft = {33, 0, false};

void IRAM_ATTR buttonRightIRS()
{
  buttonRight.numberKeyPresses += 1;
  buttonRight.pressed = true;
}

void IRAM_ATTR buttonLeftIRS()
{
  buttonLeft.numberKeyPresses += 1;
  buttonLeft.pressed = true;
}

//----------------OLED Clock----------------------------
// Define NTP Client to get time

//Wochentage
String weekDays[7] = {"Sonntag", "Montag", "Dienstag", "Mittwoch", "Donnerstag", "Freitag", "Samstag"};

//Monate
String months[12] = {"Jan", "Feb", "M""\xE4""rz", "Apr", "Mai", "Juni", "Juli", "Aug", "Sept", "Okt", "Nov", "Dez"};
//-----------------------------------------------

//char tag[7] = {'Sonntag', 'Montag ', 'Dienstag', 'Mittwoch', 'Donnerstag', 'Freitag', 'Samstag'};

//--------------Wetter-----------------------------------------------
String openWeatherMapApiKey = "b2bc7fc61c4cc3545e6bbf151b58e1dd";
String city = "Tegernsee";
String countryCode = "DE";

unsigned long lastTime = 0;
// Timer  10 Minuten (600000)
//unsigned long timerDelay = 600000;
// Timer 10 Sekunden (10000)
unsigned long timerDelay = 10000;

String jsonBuffer;
int ktemp;
int mintemp;
int maxtemp;
int sicht;
//------------------------------------------------------------------------


void setup() //-------------------------------------------------------------------------------------------------------------
{
  //------- Gas Sensor MQ135 ------------
  pinMode(Buzzer, OUTPUT);
  //    pinMode(Gas_digital, INPUT);

  pinMode(led_rot, OUTPUT);
  pinMode(led_gruen, OUTPUT);
  pinMode(led_gelb, OUTPUT);
  //----------------------------------------


  u8g2.begin();
  Serial.begin(115200);
  // setup display
  display.setBrightness(0); // Set the display brightness (0-7)!!!!!
  display.clear();          // Clear the display

  System::initFS();

  PasswordController passwordController = PasswordController("/wifi.txt");

  pinMode(buttonRight.pin, INPUT_PULLUP);
  pinMode(buttonLeft.pin, INPUT_PULLUP);
  attachInterrupt(buttonRight.pin, buttonRightIRS, FALLING);
  attachInterrupt(buttonLeft.pin, buttonLeftIRS, FALLING);

  if (!passwordController.isExisting())
  {
    isSetup = true;
  }
  else
  {
    isSetup = !System::connectToWifi(&passwordController);
  }

  if (isSetup)
  {
    WiFi.disconnect();
    WiFi.mode(WIFI_AP);
    WiFi.softAP(name, passwort);

    mdnsController.setup();

    apWebserver.setupAP();
    apWebserver.begin();
    //    Serial.println(WiFi.softAPIP());
  }

  if (isSetup)
  {
    return;
  }

  // Setup Cloudya domain local network
  mdnsController.setup();

  // Print IP Addresse
  // Serial.println(WiFi.localIP());

  // Init and get the time
  configTzTime(MY_TZ, MY_NTP_SERVER);

  struct tm timeinfo;

  if (!getLocalTime(&timeinfo))
  {
    Serial.println("Failed to obtain time");
    display.showNumberDec(0);
    return;
  }

  char timeHour[3];
  strftime(timeHour, 3, "%H", &timeinfo);
  char timeMinute[3];
  strftime(timeMinute, 3, "%M", &timeinfo);

  int displayTime = atoi(timeHour) * 100 + atoi(timeMinute);
  // Serial.println(displayTime);
  display.showNumberDecEx(displayTime, 0b11100000, true); //Display the time value;

  webserver.setup();
  webserver.begin();


  // NTPClient Zeit
  timeClient.begin();
  // timeClient.setTimeOffset(7200);

/*
  //------------ Smiley -------------------------------------------------------
  //Smiley 64x64
#define smiley_width 64
#define smiley_height 64
  static unsigned char smiley[] = {
    0x00, 0x00, 0x00, 0xd0, 0x0a, 0x00, 0x00, 0x00, 0x00, 0x00, 0x80, 0xff,
    0xff, 0x01, 0x00, 0x00, 0x00, 0x00, 0xf0, 0xff, 0xff, 0x07, 0x00, 0x00,
    0x00, 0x00, 0xfc, 0x5f, 0xfd, 0x3f, 0x00, 0x00, 0x00, 0x00, 0xff, 0x00,
    0x80, 0x7f, 0x00, 0x00, 0x00, 0x80, 0x1f, 0x00, 0x00, 0xfc, 0x01, 0x00,
    0x00, 0xe0, 0x07, 0x00, 0x00, 0xe0, 0x07, 0x00, 0x00, 0xf0, 0x01, 0x00,
    0x00, 0xc0, 0x0f, 0x00, 0x00, 0xf8, 0x00, 0x00, 0x00, 0x00, 0x1f, 0x00,
    0x00, 0x3c, 0x00, 0x00, 0x00, 0x00, 0x3e, 0x00, 0x00, 0x1e, 0x00, 0x00,
    0x00, 0x00, 0x7c, 0x00, 0x00, 0x1f, 0x00, 0x03, 0x80, 0x01, 0xf8, 0x00,
    0x80, 0x07, 0x80, 0x03, 0xc0, 0x03, 0xf0, 0x00, 0xc0, 0x07, 0x80, 0x07,
    0xc0, 0x03, 0xe0, 0x01, 0xc0, 0x03, 0xc0, 0x07, 0xc0, 0x07, 0xc0, 0x03,
    0xe0, 0x01, 0xc0, 0x07, 0xe0, 0x07, 0x80, 0x07, 0xe0, 0x00, 0xc0, 0x0f,
    0xe0, 0x07, 0x80, 0x07, 0xf0, 0x00, 0xc0, 0x0f, 0xe0, 0x07, 0x00, 0x0f,
    0x70, 0x00, 0xc0, 0x0f, 0xe0, 0x07, 0x00, 0x0e, 0x78, 0x00, 0xc0, 0x0f,
    0xe0, 0x07, 0x00, 0x1e, 0x38, 0x00, 0xe0, 0x0f, 0xe0, 0x07, 0x00, 0x1e,
    0x3c, 0x00, 0xc0, 0x0f, 0xe0, 0x07, 0x00, 0x1c, 0x1c, 0x00, 0xc0, 0x07,
    0xe0, 0x07, 0x00, 0x3c, 0x1c, 0x00, 0xc0, 0x07, 0xe0, 0x07, 0x00, 0x38,
    0x1c, 0x00, 0xc0, 0x07, 0xc0, 0x03, 0x00, 0x38, 0x1e, 0x00, 0x80, 0x07,
    0xc0, 0x03, 0x00, 0x38, 0x1e, 0x00, 0x80, 0x03, 0x80, 0x01, 0x00, 0x38,
    0x0e, 0x00, 0x00, 0x01, 0x00, 0x01, 0x00, 0x78, 0x0e, 0x00, 0x00, 0x00,
    0x00, 0x00, 0x00, 0x38, 0x0e, 0x00, 0x00, 0x00, 0x00, 0x00, 0x00, 0x78,
    0x0e, 0x00, 0x00, 0x00, 0x00, 0x00, 0x04, 0x78, 0x0e, 0x7c, 0x00, 0x00,
    0x00, 0x00, 0x3e, 0x70, 0x0e, 0x1c, 0x00, 0x00, 0x00, 0x00, 0x18, 0x38,
    0x1e, 0x10, 0x00, 0x00, 0x00, 0x00, 0x18, 0x78, 0x1e, 0x30, 0x00, 0x00,
    0x00, 0x00, 0x08, 0x38, 0x1e, 0x30, 0x00, 0x00, 0x00, 0x00, 0x08, 0x38,
    0x1c, 0x20, 0x00, 0x00, 0x00, 0x00, 0x0c, 0x38, 0x1c, 0x20, 0x00, 0x00,
    0x00, 0x00, 0x04, 0x38, 0x1c, 0x60, 0x00, 0x00, 0x00, 0x00, 0x06, 0x3c,
    0x3c, 0x40, 0x00, 0x00, 0x00, 0x00, 0x06, 0x1c, 0x38, 0xc0, 0x00, 0x00,
    0x00, 0x00, 0x03, 0x1c, 0x78, 0x80, 0x01, 0x00, 0x00, 0x00, 0x01, 0x1e,
    0x78, 0x00, 0x01, 0x00, 0x00, 0x80, 0x01, 0x0e, 0xf0, 0x00, 0x07, 0x00,
    0x00, 0xc0, 0x00, 0x0f, 0xf0, 0x00, 0x04, 0x00, 0x00, 0x60, 0x00, 0x07,
    0xe0, 0x01, 0x1c, 0x00, 0x00, 0x38, 0x80, 0x07, 0xc0, 0x03, 0x70, 0x00,
    0x00, 0x0c, 0xc0, 0x03, 0xc0, 0x03, 0xc0, 0x01, 0x00, 0x07, 0xe0, 0x03,
    0x80, 0x07, 0x80, 0x17, 0xf0, 0x01, 0xe0, 0x01, 0x00, 0x0f, 0x00, 0xfc,
    0x3f, 0x00, 0xf0, 0x00, 0x00, 0x1f, 0x00, 0x40, 0x01, 0x00, 0x78, 0x00,
    0x00, 0x3e, 0x00, 0x00, 0x00, 0x00, 0x3e, 0x00, 0x00, 0xfc, 0x00, 0x00,
    0x00, 0x00, 0x1f, 0x00, 0x00, 0xf8, 0x01, 0x00, 0x00, 0x80, 0x0f, 0x00,
    0x00, 0xe0, 0x07, 0x00, 0x00, 0xe0, 0x07, 0x00, 0x00, 0xc0, 0x1f, 0x00,
    0x00, 0xf8, 0x03, 0x00, 0x00, 0x00, 0xff, 0x00, 0x00, 0xff, 0x00, 0x00,
    0x00, 0x00, 0xfe, 0x2f, 0xf4, 0x3f, 0x00, 0x00, 0x00, 0x00, 0xf8, 0xff,
    0xff, 0x0f, 0x00, 0x00, 0x00, 0x00, 0xc0, 0xff, 0xff, 0x03, 0x00, 0x00,
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
  };

*/
//Smiley 50x50
#define smiley_width 50
#define smiley_height 50
static unsigned char smiley[] = {
   0x00, 0x00, 0x00, 0x00, 0x00, 0x00, 0x00, 0x00, 0x00, 0x00, 0x02, 0x00,
   0x00, 0x00, 0x00, 0x00, 0xfc, 0x7f, 0x00, 0x00, 0x00, 0x00, 0x00, 0xff,
   0xff, 0x03, 0x00, 0x00, 0x00, 0xc0, 0x07, 0xc0, 0x0f, 0x00, 0x00, 0x00,
   0xf0, 0x00, 0x00, 0x3e, 0x00, 0x00, 0x00, 0x3c, 0x00, 0x00, 0x78, 0x00,
   0x00, 0x00, 0x1c, 0x00, 0x00, 0xe0, 0x00, 0x00, 0x00, 0x07, 0x00, 0x00,
   0xc0, 0x01, 0x00, 0x80, 0x07, 0x00, 0x00, 0x80, 0x03, 0x00, 0x80, 0x01,
   0x08, 0xc0, 0x00, 0x07, 0x00, 0xc0, 0x01, 0x1c, 0xc0, 0x00, 0x0e, 0x00,
   0xe0, 0x00, 0x1c, 0xe0, 0x01, 0x0c, 0x00, 0x60, 0x00, 0x1e, 0xe0, 0x01,
   0x18, 0x00, 0x30, 0x00, 0x1e, 0xe0, 0x01, 0x38, 0x00, 0x30, 0x00, 0x3e,
   0xe0, 0x01, 0x30, 0x00, 0x18, 0x00, 0x1e, 0xe0, 0x01, 0x70, 0x00, 0x18,
   0x00, 0x1e, 0xe0, 0x01, 0x60, 0x00, 0x1c, 0x00, 0x1e, 0xe0, 0x01, 0x60,
   0x00, 0x0c, 0x00, 0x1c, 0xe0, 0x01, 0x60, 0x00, 0x0c, 0x00, 0x1c, 0xc0,
   0x01, 0xc0, 0x00, 0x0c, 0x00, 0x1c, 0xc0, 0x00, 0xc0, 0x00, 0x0c, 0x00,
   0x00, 0x80, 0x00, 0xc0, 0x00, 0x0c, 0x00, 0x00, 0x00, 0x00, 0xc0, 0x00,
   0x06, 0x00, 0x00, 0x00, 0x00, 0xc0, 0x00, 0x0e, 0x04, 0x00, 0x00, 0x80,
   0xc1, 0x00, 0x0c, 0x03, 0x00, 0x00, 0x00, 0xc1, 0x00, 0x0c, 0x04, 0x00,
   0x00, 0x80, 0xc0, 0x00, 0x0c, 0x04, 0x00, 0x00, 0x00, 0xc0, 0x00, 0x0c,
   0x04, 0x00, 0x00, 0x80, 0xc0, 0x00, 0x0c, 0x00, 0x00, 0x00, 0x80, 0xe0,
   0x00, 0x1c, 0x08, 0x00, 0x00, 0x40, 0x60, 0x00, 0x18, 0x08, 0x00, 0x00,
   0x40, 0x60, 0x00, 0x18, 0x10, 0x00, 0x00, 0x20, 0x70, 0x00, 0x38, 0x20,
   0x00, 0x00, 0x10, 0x30, 0x00, 0x30, 0x40, 0x00, 0x00, 0x10, 0x38, 0x00,
   0x70, 0x80, 0x00, 0x00, 0x04, 0x18, 0x00, 0x60, 0x00, 0x01, 0x00, 0x02,
   0x1c, 0x00, 0xe0, 0x00, 0x06, 0x80, 0x01, 0x0c, 0x00, 0xc0, 0x01, 0x70,
   0x30, 0x00, 0x07, 0x00, 0x80, 0x03, 0x80, 0x05, 0x00, 0x07, 0x00, 0x00,
   0x07, 0x00, 0x00, 0x80, 0x03, 0x00, 0x00, 0x0e, 0x00, 0x00, 0xe0, 0x01,
   0x00, 0x00, 0x3c, 0x00, 0x00, 0x70, 0x00, 0x00, 0x00, 0xf8, 0x00, 0x00,
   0x3c, 0x00, 0x00, 0x00, 0xe0, 0x03, 0x00, 0x1f, 0x00, 0x00, 0x00, 0x80,
   0xbf, 0xf4, 0x07, 0x00, 0x00, 0x00, 0x00, 0xfe, 0xff, 0x01, 0x00, 0x00,
   0x00, 0x00, 0xd0, 0x2f, 0x00, 0x00, 0x00, 0x00, 0x00, 0x00, 0x00, 0x00,
   0x00, 0x00 };
   



  u8g2.setFont(u8g2_font_courR10_tf);
  u8g2.firstPage();

  do {
    u8g2.clearBuffer();
    u8g2.drawXBM(40, 0, smiley_width, smiley_height, smiley);
        u8g2.setCursor(12, 62);
        u8g2.setFont(u8g2_font_courB08_tf);
        u8g2.print("Ich lade die Daten");

    
  } while ( u8g2.nextPage() );
  delay(3000);

  //----------------------------------------------------------------------------------
//FastLED.setBrightness(100);

} //Ende Setup
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

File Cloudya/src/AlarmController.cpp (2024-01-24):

#include <Arduino.h>
#include "AlarmController.h"

// Define the pin for the buzzer and configurate it:
#define BUZ 4
int freq = 2000;
int channel = 0;
int resolution = 8;

AlarmController::AlarmController(LightController *_lightController)
{
    lightController = _lightController;
    alarmHour = 8;
    alarmMinute = 0;
    alarmStatus = false;
    snoozeMinute = 5;

    // setup buzzer
    ledcSetup(channel, freq, resolution);
    ledcAttachPin(BUZ, channel);
}

void AlarmController::on()
{
    alarmStatus = true;
}

void AlarmController::off()
{
    alarmStatus = false;
}

void AlarmController::setAlarm(int hour, int minute)
{
    alarmHour = hour;
    alarmMinute = minute;
}

void AlarmController::makeNoise()
{
    ledcWrite(channel, 150);
    ledcWriteTone(channel, 4000);
    delay(100);
    ledcWriteTone(channel, 0);
    delay(500);
    ledcWriteTone(channel, 4000);
    delay(100);
    ledcWriteTone(channel, 0);
}

void AlarmController::snooze()
{
    if (beeping)
    {
        beeping = false;
        snoozeCount++;
    }
}

void AlarmController::stopAlarm()
{
    if (beeping)
    {
        beeping = false;
        alarmStopped = true;
    }
}

void AlarmController::loop(int hour, int minute)
{
    if (compareAlarmMinutes(hour, minute, 0) && getAlarmStatus())
    {
        beeping = true;
        makeNoise();
        lightController->flash_white();
    }
    else
    {
        if (compareAlarmMinutes(hour, minute, 1))
        {
            snoozeCount = 0;
            alarmStopped = false;
            beeping = false;
        }
    }
}

bool AlarmController::getAlarmStatus() { return alarmStatus && !alarmStopped; }

int AlarmController::getHour() { return alarmHour; }

int AlarmController::getMinute() { return alarmMinute; }

bool AlarmController::compareAlarmMinutes(int hour, int minute, int offset)
{
    int alarmMinutes = (alarmHour * 60) + alarmMinute + (snoozeMinute * snoozeCount);
    int currentMinutes = (hour * 60) + minute;
    return (alarmMinutes + offset) == currentMinutes;
}

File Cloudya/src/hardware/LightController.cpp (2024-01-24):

#include <Arduino.h>
#include <FastLED.h>
#include "LightController.h"

// fastLED configuration:
#define NUM_LEDS 20 // set number of LEDs here
#define LED_PIN 14
#define LED_TYPE WS2811
#define COLOR_ORDER GRB
CRGB leds[NUM_LEDS]; // Define the array of ledsw

int x = 0;
bool up = true;

LightController::LightController()
{
  red = 0;
  blue = 255;
  green = 127;
  intensity = 6;
  FastLED.addLeds<LED_TYPE, LED_PIN, COLOR_ORDER>(leds, NUM_LEDS).setCorrection(TypicalLEDStrip);
  fill_solid(leds, NUM_LEDS, CRGB(0, 255, 127));
}

void LightController::on()
{
  FastLED.setBrightness(intensity);
  FastLED.show();
}

void LightController::off()
{
  FastLED.setBrightness(0);
  FastLED.show();
}



void LightController::setRGB(int _red, int _green, int _blue)
{
  red = _red;
  green = _green;
  blue = _blue;
  fill_solid(leds, NUM_LEDS, CRGB(red, green, blue));
}

void LightController::setIntenstiy(int _intensity)
{
  intensity = _intensity;
}

void LightController::bounce()
{
  EVERY_N_MILLIS(50)
  {
    Serial.println(x);
    fill_solid(leds, NUM_LEDS, CRGB(0, 0, 0));
    leds[x] = CRGB(255, 255, 255);
    leds[x + 1] = CRGB(255, 255, 255);
    leds[x + 2] = CRGB(255, 255, 255);
    FastLED.show();

    if (x < NUM_LEDS - 3 && up)
    {
      x++;
    }
    else if (x == NUM_LEDS - 3 && up)
    {
      up = false;
      x--;
    }
    else if (x == 0 && !up)
    {
      up = true;
    }
    else
    {
      x--;
    }
  }
}

void LightController::runner()
{
  EVERY_N_MILLIS(100)
  {
    Serial.print(x);
    fill_solid(leds, NUM_LEDS, CRGB(0, 0, 0));
    leds[x] = CRGB(255, 255, 255);
    if (x > 0)
    {
      leds[x - 1] = CRGB(255, 255, 255);
      Serial.print(x) - 1;
    }
    else
    {
      leds[NUM_LEDS - 2] = CRGB(255, 255, 255);
    }

    if (x > 1)
    {
      leds[x - 2] = CRGB(255, 255, 255);
      Serial.println(x - 2);
    }
    else
    {
      leds[NUM_LEDS - 1] = CRGB(255, 255, 255);
      Serial.print(NUM_LEDS - 1);
    }

    FastLED.show();

    if (x < NUM_LEDS)
    {
      x++;
    }
    else
    {
      x = 0;
    }
  }
}

void LightController::pulse()
{

  EVERY_N_MILLIS(20)
  {

    FastLED.setBrightness(x);

    if (x < 255 && up)
    {
      x++;
    }
    else if (x == 255 && up)
    {
      up = false;
      x--;
    }
    else if (x == 0 && !up)
    {
      up = true;
    }
    else
    {
      x--;
    }
    FastLED.show();
  }
}

void LightController::flash_white()
{
  fill_solid(leds, NUM_LEDS, CRGB(255, 255, 255));

  EVERY_N_MILLIS(500)
  {
    FastLED.setBrightness(255);
    FastLED.show();
  }

  EVERY_N_MILLIS(300)
  {
    FastLED.setBrightness(0);
    FastLED.show();
  }
}

void LightController::setPattern() {}

int LightController::getIntenstiy() { return intensity; }

int LightController::getRed() { return red; }

int LightController::getGreen() { return green; }

int LightController::getBlue() { return blue; }

bool LightController::isActive() { return FastLED.getBrightness() > 0; }
